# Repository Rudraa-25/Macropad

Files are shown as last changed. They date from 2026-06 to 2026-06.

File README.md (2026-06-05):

# ESP32-C3 Custom Macropad ⌨️

A fully open-source, DIY Bluetooth Macropad built with an ESP32-C3, featuring an OLED display and a dynamic **Web Bluetooth** configuration app. Configure your keymaps instantly from the web, completely wirelessly!

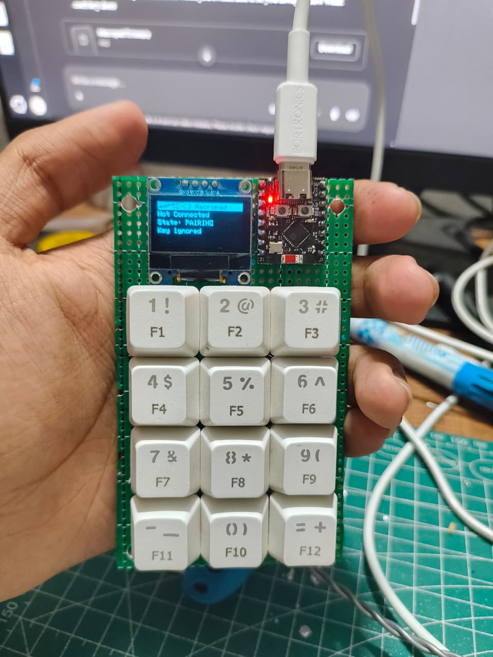
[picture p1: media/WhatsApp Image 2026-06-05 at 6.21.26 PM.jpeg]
Macropad Showcase


## ✨ Features

- **True Wireless**: Acts as a BLE (Bluetooth Low Energy) HID Keyboard. No USB required for normal use.
- **Battery Powered & Wireless**: Takes advantage of the ESP32's power efficiency to run completly on battery. Truly wireless setup for your desk!
- **Instant Web Configuration**: Includes a beautiful web application (`web-app/`) built with React and Web Bluetooth API. Re-map your keys, layers, and media controls straight from your browser without installing *any* drivers or softwere.
- **OLED Display**: Built-in SSD1306 OLED display for showing the current layer, sent keystrokes, and connetion status.
- **Multi-Layer Support**: Toggle between different key layers instantly.
- **Zero-Latency Binary Protocol**: Uses a highly optimized 384-byte binary GATT protocol to instantly fetch and save your keymap layout.

---

## 📂 Repository Structure

```
├── firmware/       # ESP32-C3 Arduino firmware code (.ino)
├── hardware/       # KiCad schematics and PDF blueprints
├── web-app/        # React + Vite web configuration tool (Vercel ready)
└── media/          # Images and video showcases of the build
```

---

## 🛠️ Hardware Requirements

- **ESP32-C3** Microcontroller
- 12x Mechanical Switches (4 Rows x 3 Cols)
- SSD1306 OLED Display (I2C)
- Custom PCB or Handwired Matrix (See `hardware/output.pdf` for the schamatic)

### Media & Build Process
Here are some behind-the-scenes looks at the build:
Schematic Process

*(More images and videos can be found in the `media/` folder!)*

---

## 🚀 Getting Started

### 1. Flash the Firmware
1. Open `firmware/Macropad.ino` in the Arduino IDE.
2. Install the required librarys (`NimBLE-Arduino`, `Adafruit GFX`, `Adafruit SSD1306`).
3. Select your ESP32-C3 board and flash it.

### 2. Pair with your OS (Important!)
Because the device acts as a secure HID Keyboard, you **must pair it in your OS settings first** (Windows/Mac/Linux) before the Web App can communicate with it.

1. Power on the ESP32-C3 Macropad.
2. Go to your computer's Bluetooth Settings and click "Add Device".
3. Pair with **"ESP32-C3 Macropad"**.

### 3. Deploy the Web App
The `web-app` folder contains the frontend configurator. You can deploy it for free using **Vercel** with zero configuration:

Deploy with Vercel (https://vercel.com/new/clone?repository-url=https://github.com/Rudraa-25/Macropad/tree/main/web-app)

Alternatively, to run it locally:
```bash
cd web-app
npm install
npm run dev
```

### 4. Configure Your Keys
1. Open your deployed web app in Google Chrome or Microsoft Edge (Safari/Firefox do not support Web Bluetooth).
2. Click **Connect Device**.
3. Re-map your keys and click Save!

---

## 🤝 Contributing
Feel free to open issues or submit pull requests. All hardware designs, firmware code, and web application code are completly open-source!

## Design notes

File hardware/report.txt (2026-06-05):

Info: Processing symbol 'SW3:'.
Info: Processing symbol 'D12:Diode_THT:D_DO-35_SOD27_P7.62mm_Horizontal'.
Info: Processing symbol 'D11:Diode_THT:D_DO-35_SOD27_P7.62mm_Horizontal'.
Info: Processing symbol 'D7:Diode_THT:D_DO-35_SOD27_P7.62mm_Horizontal'.
Info: Processing symbol 'D6:Diode_THT:D_DO-35_SOD27_P7.62mm_Horizontal'.
Info: Processing symbol 'D9:Diode_THT:D_DO-35_SOD27_P7.62mm_Horizontal'.
Info: Processing symbol 'D3:Diode_THT:D_DO-35_SOD27_P7.62mm_Horizontal'.
Info: Processing symbol 'D10:Diode_THT:D_DO-35_SOD27_P7.62mm_Horizontal'.
Info: Processing symbol 'D5:Diode_THT:D_DO-35_SOD27_P7.62mm_Horizontal'.
Info: Processing symbol 'D1:Diode_THT:D_DO-35_SOD27_P7.62mm_Horizontal'.
Info: Processing symbol 'D4:Diode_THT:D_DO-35_SOD27_P7.62mm_Horizontal'.
Info: Processing symbol 'SW1:'.
Info: Processing symbol 'SW2:'.
Info: Processing symbol 'SW4:'.
Info: Processing symbol 'D2:Diode_THT:D_DO-35_SOD27_P7.62mm_Horizontal'.
Info: Total warnings: 0, errors: 14.
Info: Processing symbol 'D8:Diode_THT:D_DO-35_SOD27_P7.62mm_Horizontal'.
Info: Processing symbol 'U2:DM-OLED096-636:MODULE_DM-OLED096-636'.
Info: Processing symbol 'U1:ESP32-C3_SUPERMINI_TH:MODULE_ESP32-C3_SUPERMINI_TH'.
Info: Processing symbol 'SW12:'.
Info: Processing symbol 'SW11:'.
Info: Processing symbol 'SW10:'.
Info: Processing symbol 'SW9:'.
Info: Processing symbol 'SW8:'.
Info: Processing symbol 'SW7:'.
Info: Processing symbol 'SW6:'.
Info: Processing symbol 'SW5:'.
Updated D9 sheetname to '/'.
Updated D9 sheetfile to 'macropad_schamatic.kicad_sch'.
Updated D9 footprint filters to 'D*DO?35*'.
Updated D9 fields.
Updated D10 symbol association from  to /3b1d06b9-a825-4d46-bb26-167e9ae0420c.
Add net Net-(D9-A).
Connected D9 pin 2 to Net-(D9-A).
Connected D9 pin 1 to /Row3.
Added D10 (footprint 'Diode_THT:D_DO-35_SOD27_P7.62mm_Horizontal').
Changed REF** reference designator to D10.
Changed D10 value from D_DO-35_SOD27_P7.62mm_Horizontal to 1N4148.
Connected D7 pin 2 to Net-(D7-A).
Updated D9 symbol association from  to /199a567d-7bb4-44c4-a2eb-34c93029b7e5.
Changed D9 value from D_DO-35_SOD27_P7.62mm_Horizontal to 1N4148.
Changed REF** reference designator to D9.
Added D9 (footprint 'Diode_THT:D_DO-35_SOD27_P7.62mm_Horizontal').
Connected D8 pin 1 to /Row3.
Connected D8 pin 2 to Net-(D8-A).
Add net Net-(D8-A).
Updated D8 footprint filters to 'D*DO?35*'.
Updated D8 sheetfile to 'macropad_schamatic.kicad_sch'.
Updated D8 sheetname to '/'.
Updated D8 fields.
Updated D8 symbol association from  to /9f40b5d8-0e24-43d8-8150-3eca3353b136.
Changed D8 value from D_DO-35_SOD27_P7.62mm_Horizontal to 1N4148.
Added D8 (footprint 'Diode_THT:D_DO-35_SOD27_P7.62mm_Horizontal').
Changed REF** reference designator to D8.
Connected D11 pin 1 to /Row4.

Connected D12 pin 2 to Net-(D12-A).
Add net Net-(D12-A).
Connected D12 pin 1 to /Row4.
Updated D12 footprint filters to 'D*DO?35*'.
Updated D12 sheetfile to 'macropad_schamatic.kicad_sch'.
Updated D12 sheetname to '/'.
Updated D12 fields.
Updated D12 symbol association from  to /22c7e66f-c951-40f0-a668-87876b066d72.
Changed D12 value from D_DO-35_SOD27_P7.62mm_Horizontal to 1N4148.
Changed REF** reference designator to D12.
Added D12 (footprint 'Diode_THT:D_DO-35_SOD27_P7.62mm_Horizontal').
Connected D11 pin 2 to Net-(D11-A).
Add net Net-(D11-A).
Updated D10 fields.
Updated D11 footprint filters to 'D*DO?35*'.
Updated D11 sheetfile to 'macropad_schamatic.kicad_sch'.
Updated D11 sheetname to '/'.
Updated D11 fields.
Updated D11 symbol association from  to /56b49147-e174-4669-9fb5-d7634ec6eaf1.
Changed D11 value from D_DO-35_SOD27_P7.62mm_Horizontal to 1N4148.
Changed REF** reference designator to D11.
Added D11 (footprint 'Diode_THT:D_DO-35_SOD27_P7.62mm_Horizontal').
Connected D10 pin 1 to /Row4.
Add net /Row4.
Connected D10 pin 2 to Net-(D10-A).
Add net Net-(D10-A).
Updated D10 footprint filters to 'D*DO?35*'.
Updated D10 sheetfile to 'macropad_schamatic.kicad_sch'.
Updated D10 sheetname to '/'.
Updated D3 sheetfile to 'macropad_schamatic.kicad_sch'.
Add net Net-(D2-A).
Connected D2 pin 2 to Net-(D2-A).
Connected D2 pin 1 to /Row1.
Added D3 (footprint 'Diode_THT:D_DO-35_SOD27_P7.62mm_Horizontal').
Changed REF** reference designator to D3.
Changed D3 value from D_DO-35_SOD27_P7.62mm_Horizontal to 1N4148.
Updated D3 symbol association from  to /08482ce4-6621-43d8-9687-0b48ae680ee7.
Updated D3 fields.
Updated D3 sheetname to '/'.
Updated D2 footprint filters to 'D*DO?35*'.
Updated D3 footprint filters to 'D*DO?35*'.
Connected D3 pin 1 to /Row1.
Add net Net-(D7-A).
Connected D3 pin 2 to Net-(D3-A).
Added D4 (footprint 'Diode_THT:D_DO-35_SOD27_P7.62mm_Horizontal').
Changed REF** reference designator to D4.
Changed D4 value from D_DO-35_SOD27_P7.62mm_Horizontal to 1N4148.
Updated D4 symbol association from  to /e49631f5-7ebc-4f1f-bee1-7b618c591ae1.
Updated D4 fields.
Connected D1 pin 2 to Net-(D1-A).
Added D1 (footprint 'Diode_THT:D_DO-35_SOD27_P7.62mm_Horizontal').
Changed REF** reference designator to D1.
Changed D1 value from D_DO-35_SOD27_P7.62mm_Horizontal to 1N4148.
Updated D1 symbol association from  to /219e1ffa-72e7-460a-b503-95e3a15a7402.
Updated D1 fields.
Updated D1 sheetname to '/'.
Updated D1 sheetfile to 'macropad_schamatic.kicad_sch'.
Updated D1 footprint filters to 'D*DO?35*'.
Add net Net-(D1-A).
Add net Net-(D3-A).
Add net /Row1.
Connected D1 pin 1 to /Row1.
Added D2 (footprint 'Diode_THT:D_DO-35_SOD27_P7.62mm_Horizontal').
Changed REF** reference designator to D2.
Changed D2 value from D_DO-35_SOD27_P7.62mm_Horizontal to 1N4148.
Updated D2 symbol association from  to /d1962255-4c64-4023-9314-8b50c877019e.
Updated D2 fields.
Updated D2 sheetname to '/'.
Updated D2 sheetfile to 'macropad_schamatic.kicad_sch'.
Added D7 (footprint 'Diode_THT:D_DO-35_SOD27_P7.62mm_Horizontal').
Changed D6 value from D_DO-35_SOD27_P7.62mm_Horizontal to 1N4148.
Updated D6 symbol association from  to /b3993612-8098-4776-a2f9-317e4327c308.
Updated D6 fields.
Updated D6 sheetname to '/'.
Updated D4 sheetname to '/'.
Updated D6 footprint filters to 'D*DO?35*'.
Add net Net-(D6-A).
Connected D6 pin 2 to Net-(D6-A).
Connected D6 pin 1 to /Row2.
Updated D6 sheetfile to 'macropad_schamatic.kicad_sch'.
Changed REF** reference designator to D7.
Changed D7 value from D_DO-35_SOD27_P7.62mm_Horizontal to 1N4148.
Updated D7 symbol association from  to /181c0100-887a-4238-aaa2-16277b3d4ceb.
Updated D7 fields.
Updated D7 sheetname to '/'.
Updated D7 sheetfile to 'macropad_schamatic.kicad_sch'.
Updated D7 footprint filters to 'D*DO?35*'.
Add net /Row3.
Connected D7 pin 1 to /Row3.
Updated D5 symbol association from  to /a2443731-23b2-4b6e-a306-a3f56fe90480.
Updated D4 sheetfile to 'macropad_schamatic.kicad_sch'.
Updated D4 footprint filters to 'D*DO?35*'.
Add net Net-(D4-A).
Connected D4 pin 2 to Net-(D4-A).
Add net /Row2.
Connected D4 pin 1 to /Row2.
Added D5 (footprint 'Diode_THT:D_DO-35_SOD27_P7.62mm_Horizontal').
Changed REF** reference designator to D5.
Changed D5 value from D_DO-35_SOD27_P7.62mm_Horizontal to 1N4148.
Changed REF** reference designator to D6.
Updated D5 fields.
Added D6 (footprint 'Diode_THT:D_DO-35_SOD27_P7.62mm_Horizontal').
Connected D5 pin 2 to Net-(D5-A).
Updated D5 sheetfile to 'macropad_schamatic.kicad_sch'.
Add net Net-(D5-A).
Updated D5 footprint filters to 'D*DO?35*'.
Updated D5 sheetname to '/'.
Connected D5 pin 1 to /Row2.
Error: Cannot add SW3 (no footprint assigned).
Error: Cannot add SW1 (no footprint assigned).
Error: Cannot add U2 (footprint 'DM-OLED096-636:MODULE_DM-OLED096-636' not found).
Error: Cannot add U1 (footprint 'ESP32-C3_SUPERMINI_TH:MODULE_ESP32-C3_SUPERMINI_TH' not found).
Error: Cannot add SW2 (no footprint assigned).
Error: Cannot add SW12 (no footprint assigned).
Error: Cannot add SW11 (no footprint assigned).
Error: Cannot add SW10 (no footprint assigned).
Error: Cannot add SW9 (no footprint assigned).
Error: Cannot add SW4 (no footprint assigned).
Error: Cannot add SW8 (no footprint assigned).
Error: Cannot add SW7 (no footprint assigned).
Error: Cannot add SW5 (no footprint assigned).
Error: Cannot add SW6 (no footprint assigned).

Info: Total warnings: 0, errors: 14.

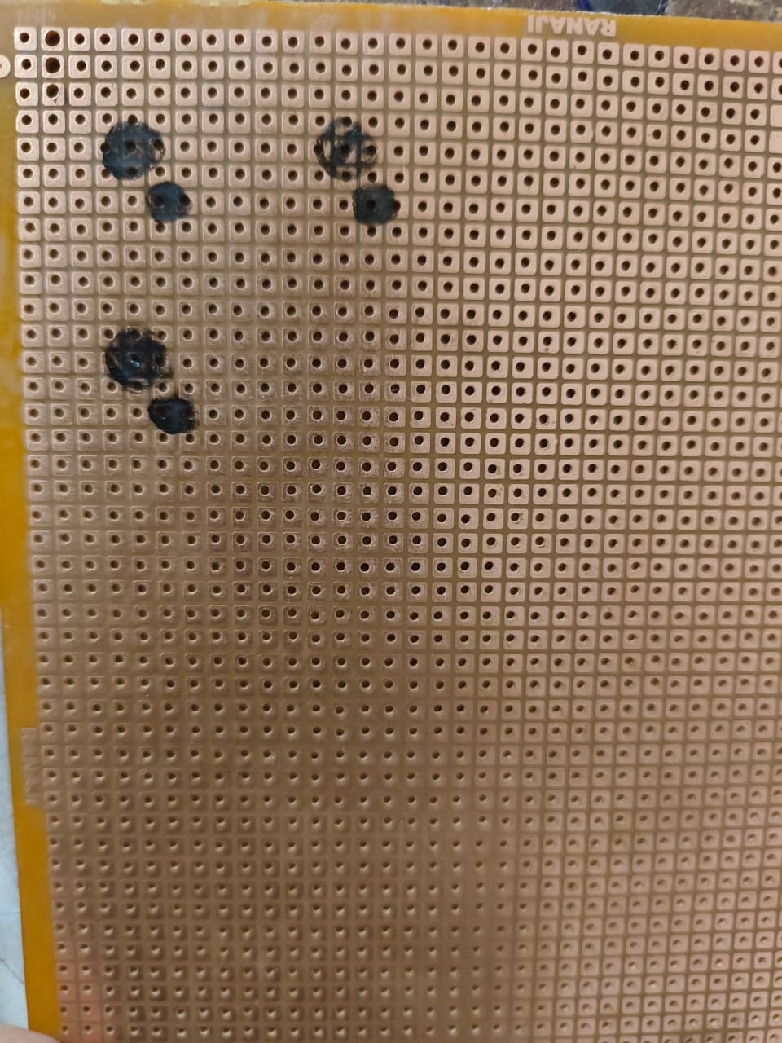
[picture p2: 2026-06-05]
media/WhatsApp Image 2026-06-05 at 6.21.24 PM.jpeg

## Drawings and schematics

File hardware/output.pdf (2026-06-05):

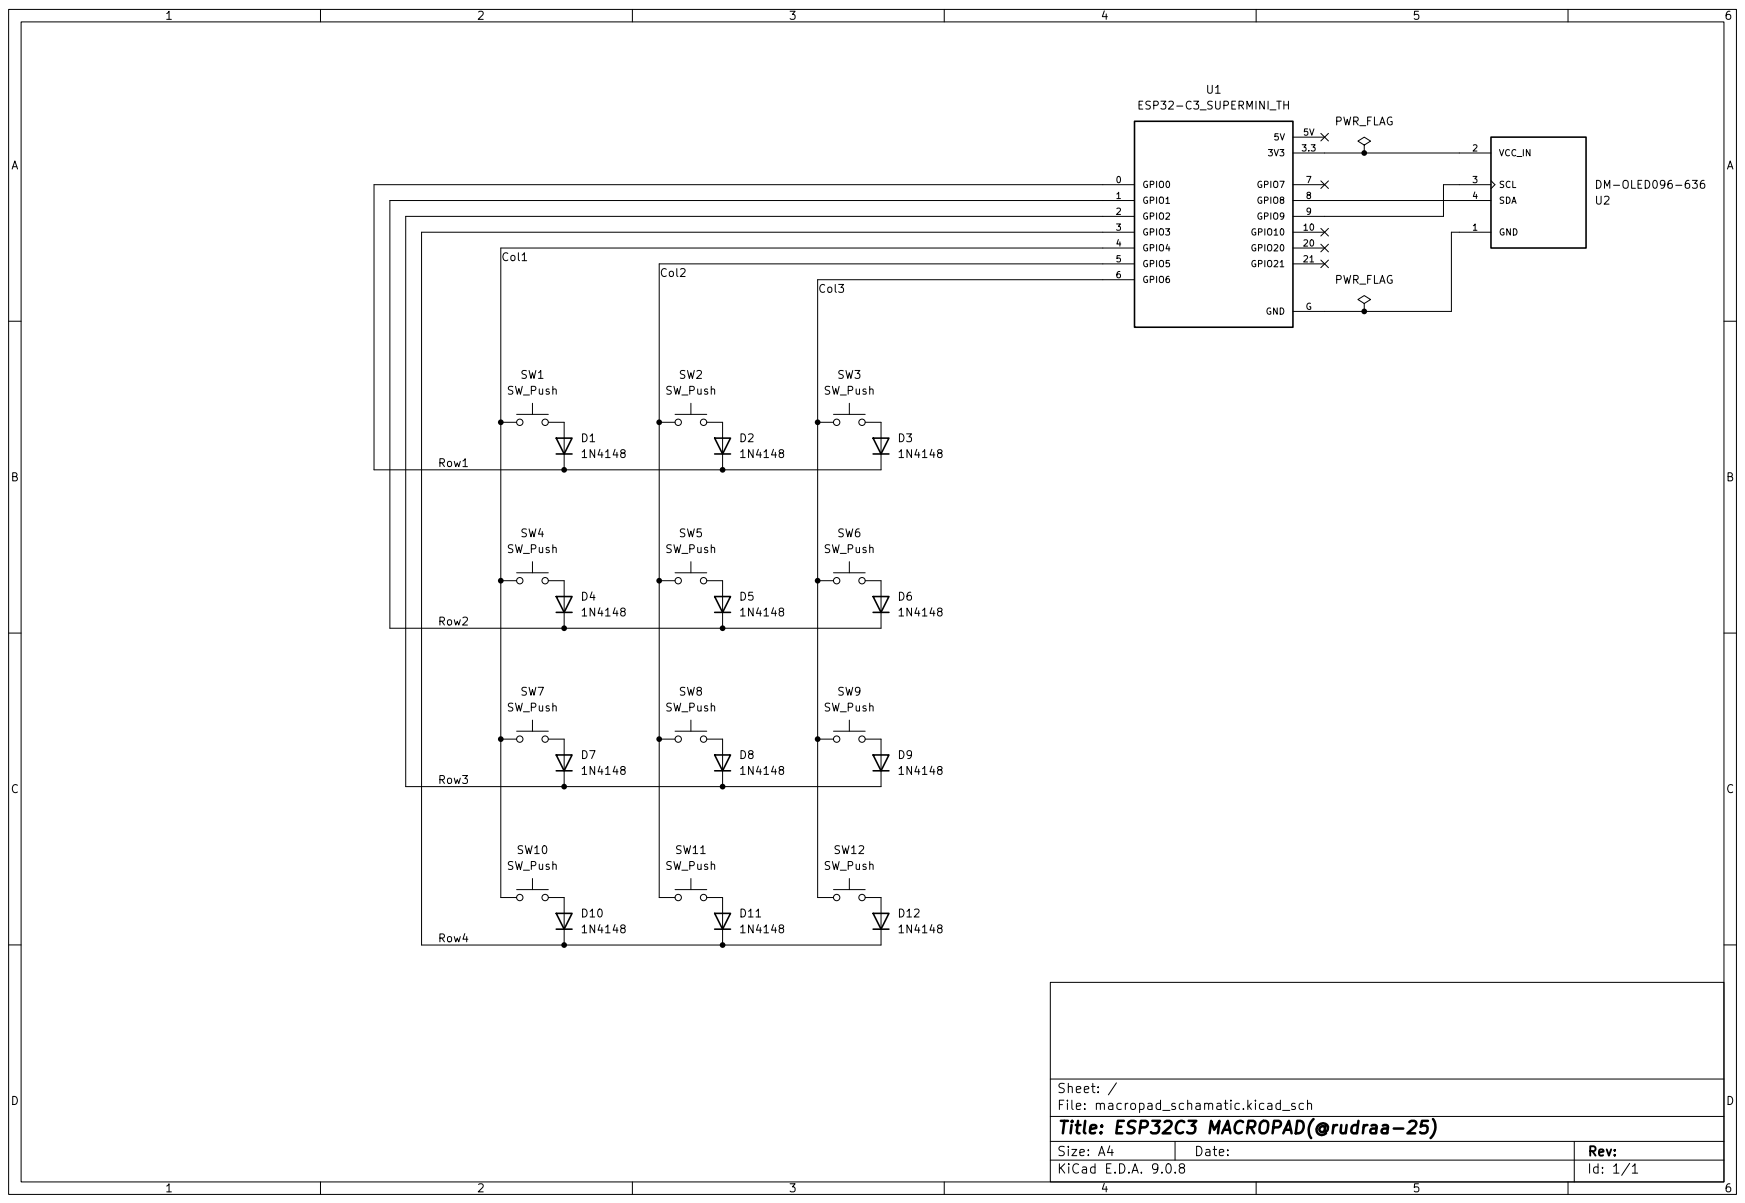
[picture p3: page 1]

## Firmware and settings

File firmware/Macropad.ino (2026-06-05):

// ============================================================
//  ESP32-C3 BLE Macropad -- Firmware v8
//
//  ARCHITECTURE CHANGE FROM v7:
//    WiFi / config mode REMOVED entirely.
//    The device is ALWAYS a BLE keyboard.
//    Configuration is done via a second BLE GATT service
//    running alongside the HID service.
//    The Lovable web app uses Web Bluetooth API to connect
//    and read/write keymap characteristics directly.
//
//  BLE SERVICES:
//    1. HID Service (standard)       -- keyboard input
//    2. Config Service (custom GATT) -- keymap read/write
//       Service UUID:  12345678-1234-1234-1234-1234567890AB
//       Characteristics:
//         STATUS_UUID:  read  -- JSON device info
//         KEYMAP_UUID:  read  -- full keymap JSON
//         SAVE_UUID:    write -- post updated keymap JSON
//
//  HOW TO USE:
//    Just power on -- it advertises as a BLE keyboard AND config target.
//    Open the Lovable web app in Chrome/Edge on phone or desktop.
//    Click "Connect Device" -- browser shows BLE pairing dialog.
//    Select "ESP32-C3 Macropad" -- app reads keymap, lets you edit, saves.
//    Keyboard still works while config app is connected.
// ============================================================

#include <Arduino.h>
#include <Preferences.h>
#include <Wire.h>
#include <Adafruit_GFX.h>
#include <Adafruit_SSD1306.h>
#include <NimBLEDevice.h>
#include <NimBLEServer.h>
#include <NimBLEUtils.h>
#include <NimBLEHIDDevice.h>
#include <HIDTypes.h>

// ============================================================
//  CONFIG
// ============================================================
#define DEVICE_NAME       "ESP32-C3 Macropad"
#define MANUFACTURER_NAME "DIY"

// Custom GATT UUIDs for the config service
// These must match exactly in the Lovable web app
#define CONFIG_SERVICE_UUID  "12345678-1234-1234-1234-1234567890ab"
#define STATUS_CHAR_UUID     "12345678-1234-1234-1234-1234567890ac"
#define KEYMAP_CHAR_UUID     "12345678-1234-1234-1234-1234567890ad"
#define SAVE_CHAR_UUID       "12345678-1234-1234-1234-1234567890ae"

// ============================================================
//  OLED
// ============================================================
#define SCREEN_W   128
#define SCREEN_H    64
#define OLED_ADDR  0x3C
#define OLED_SDA     8
#define OLED_SCL     9

// ============================================================
//  MATRIX
// ============================================================
#define ROWS 4
#define COLS 3
const int rowPins[ROWS] = {0, 1, 2, 3};
const int colPins[COLS] = {5, 6, 7};

#define DEBOUNCE_MS    150
#define ADV_RESTART_MS 500
#define MTU_SIZE       512   // increased for keymap JSON transfer
#define NUM_KEYS       (ROWS * COLS)
#define NUM_LAYERS     2

// ============================================================
//  HID constants
// ============================================================
#define MOD_NONE  0x00
#define MOD_CTRL  0x01
#define MOD_SHIFT 0x02
#define MOD_ALT   0x04
#define MOD_GUI   0x08

#define KEY_NONE  0x00
#define KEY_0     0x27
#define KEY_1     0x1E
#define KEY_2     0x1F
#define KEY_3     0x20
#define KEY_4     0x21
#define KEY_5     0x22
#define KEY_6     0x23
#define KEY_7     0x24
#define KEY_8     0x25
#define KEY_9     0x26
#define KEY_A     0x04
#define KEY_B     0x05
#define KEY_C     0x06
#define KEY_D     0x07
#define KEY_E     0x08
#define KEY_F     0x09
#define KEY_G     0x0A
#define KEY_H     0x0B
#define KEY_I     0x0C
#define KEY_J     0x0D
#define KEY_K     0x0E
#define KEY_L     0x0F
#define KEY_M     0x10
#define KEY_N     0x11
#define KEY_O     0x12
#define KEY_P     0x13
#define KEY_Q     0x14
#define KEY_R     0x15
#define KEY_S     0x16
#define KEY_T     0x17
#define KEY_U     0x18
#define KEY_V     0x19
#define KEY_W     0x1A
#define KEY_X     0x1B
#define KEY_Y     0x1C
#define KEY_Z     0x1D
#define KEY_F1    0x3A
#define KEY_F2    0x3B
#define KEY_F3    0x3C
#define KEY_F4    0x3D
#define KEY_F5    0x3E
#define KEY_F6    0x3F
#define KEY_F7    0x40
#define KEY_F8    0x41
#define KEY_F9    0x42
#define KEY_F10   0x43
#define KEY_F11   0x44
#define KEY_F12   0x45
#define KEY_ESC   0x29
#define KEY_TAB   0x2B
#define KEY_DEL   0x4C
#define KEY_HOME  0x4A
#define KEY_END   0x4D
#define KEY_PGUP  0x4B
#define KEY_PGDN  0x4E
#define KEY_UP    0x52
#define KEY_DOWN  0x51
#define KEY_LEFT  0x50
#define KEY_RIGHT 0x4F
#define KEY_ENTER 0x28
#define KEY_SPACE 0x2C
#define KEY_BKSP  0x2A

#define CONSUMER_VOL_UP   0xE9
#define CONSUMER_VOL_DOWN 0xEA
#define CONSUMER_MUTE     0xE2

#define ACTION_NONE         0
#define ACTION_LAYER_TOGGLE 1
#define ACTION_VOLUME_UP    2
#define ACTION_VOLUME_DOWN  3
#define ACTION_MUTE         4

// ============================================================
//  Data
// ============================================================
struct KeyDef {
  uint8_t mod;
  uint8_t keycode;
  uint8_t action;
  char    label[12];
};

KeyDef keyMap[NUM_LAYERS][ROWS][COLS] = {
  // Layer 0: Numbers
  {
    { {MOD_NONE,KEY_1,ACTION_NONE,"1"},    {MOD_NONE,KEY_2,ACTION_NONE,"2"},    {MOD_NONE,KEY_3,ACTION_NONE,"3"}    },
    { {MOD_NONE,KEY_4,ACTION_NONE,"4"},    {MOD_NONE,KEY_5,ACTION_NONE,"5"},    {MOD_NONE,KEY_6,ACTION_NONE,"6"}    },
    { {MOD_NONE,KEY_7,ACTION_NONE,"7"},    {MOD_NONE,KEY_8,ACTION_NONE,"8"},    {MOD_NONE,KEY_9,ACTION_NONE,"9"}    },
    { {MOD_NONE,KEY_NONE,ACTION_VOLUME_UP,"VolUp"}, {MOD_NONE,KEY_0,ACTION_NONE,"0"}, {MOD_NONE,KEY_NONE,ACTION_LAYER_TOGGLE,"MODE"} },
  },
  // Layer 1: Shortcuts
  {
    { {MOD_CTRL,KEY_Z,ACTION_NONE,"Ctrl+Z"}, {MOD_CTRL,KEY_S,ACTION_NONE,"Ctrl+S"}, {MOD_CTRL,KEY_A,ACTION_NONE,"Ctrl+A"} },
    { {MOD_CTRL,KEY_X,ACTION_NONE,"Ctrl+X"}, {MOD_CTRL,KEY_Y,ACTION_NONE,"Ctrl+Y"}, {MOD_GUI, KEY_D,ACTION_NONE,"Win+D"}  },
    { {MOD_ALT, KEY_F4,ACTION_NONE,"Alt+F4"},{MOD_CTRL,KEY_W,ACTION_NONE,"Ctrl+W"}, {MOD_CTRL,KEY_T,ACTION_NONE,"Ctrl+T"} },
    { {MOD_NONE,KEY_NONE,ACTION_VOLUME_DOWN,"VolDn"}, {MOD_NONE,KEY_0,ACTION_NONE,"0"}, {MOD_NONE,KEY_NONE,ACTION_LAYER_TOGGLE,"MODE"} },
  }
};

// ============================================================
//  Globals
// ============================================================
Preferences            prefs;
NimBLEHIDDevice*       hid           = nullptr;
NimBLECharacteristic*  inputKbd      = nullptr;
NimBLECharacteristic*  inputConsumer = nullptr;
NimBLEServer*          pServer       = nullptr;
NimBLECharacteristic*  cfgStatusChar = nullptr;
NimBLECharacteristic*  cfgKeymapChar = nullptr;
NimBLECharacteristic*  cfgSaveChar   = nullptr;
Adafruit_SSD1306       display(SCREEN_W, SCREEN_H, &Wire, -1);
bool                   oledOk        = false;
int                    currentLayer  = 0;
bool                   configClientConnected = false;

enum class BleState { INIT, ADVERTISING, PAIRING, CONNECTED, DISCONNECTED };
volatile BleState bleState  = BleState::INIT;
volatile bool     needReAdv = false;
uint32_t          connectedAt = 0;

// ============================================================
//  Forward declarations
// ============================================================
void updateOLED(const char* l1, const char* l2, const char* l3, const char* l4 = "");
void startAdvertising();
void sendKey(uint8_t mod, uint8_t kc);
void sendConsumer(uint8_t usage);
void showLayerScreen();
void saveKeyMap();
void loadKeyMap();
const char* stateName(BleState s);
String buildKeymapJson();
bool parseAndApplyKeymap(const String& json);

// ============================================================
//  NVS
// ============================================================
void saveKeyMap() {
  prefs.begin("keymap", false);
  for (int layer = 0; layer < NUM_LAYERS; layer++) {
    for (int r = 0; r < ROWS; r++) {
      for (int c = 0; c < COLS; c++) {
        int idx = layer * NUM_KEYS + r * COLS + c;
        char km[8], kk[8], ka[8], kl[8];
        snprintf(km,8,"m%d",idx); snprintf(kk,8,"k%d",idx);
        snprintf(ka,8,"a%d",idx); snprintf(kl,8,"l%d",idx);
        prefs.putUChar(km, keyMap[layer][r][c].mod);
        prefs.putUChar(kk, keyMap[layer][r][c].keycode);
        prefs.putUChar(ka, keyMap[layer][r][c].action);
        prefs.putString(kl, keyMap[layer][r][c].label);
      }
    }
  }
  prefs.end();
  Serial.println("[NVS] Saved");
}

void loadKeyMap() {
  prefs.begin("keymap", true);
  if (!prefs.isKey("m0")) { prefs.end(); Serial.println("[NVS] Using defaults"); return; }
  for (int layer = 0; layer < NUM_LAYERS; layer++) {
    for (int r = 0; r < ROWS; r++) {
      for (int c = 0; c < COLS; c++) {
        int idx = layer * NUM_KEYS + r * COLS + c;
        char km[8], kk[8], ka[8], kl[8];
        snprintf(km,8,"m%d",idx); snprintf(kk,8,"k%d",idx);
        snprintf(ka,8,"a%d",idx); snprintf(kl,8,"l%d",idx);
        keyMap[layer][r][c].mod     = prefs.getUChar(km, keyMap[layer][r][c].mod);
        keyMap[layer][r][c].keycode = prefs.getUChar(kk, keyMap[layer][r][c].keycode);
        keyMap[layer][r][c].action  = prefs.getUChar(ka, keyMap[layer][r][c].action);
        String lbl = prefs.getString(kl, keyMap[layer][r][c].label);
        strncpy(keyMap[layer][r][c].label, lbl.c_str(), 11);
        keyMap[layer][r][c].label[11] = '\0';
      }
    }
  }
  prefs.end();
  Serial.println("[NVS] Loaded");
}

// ============================================================
//  JSON helpers
// ============================================================
String buildKeymapJson() {
  // Compact JSON: {"layers":2,"keys":12,"keymap":[[{...},...],[...]]}
  String s = "{\"layers\":";
  s += NUM_LAYERS;
  s += ",\"keys\":";
  s += NUM_KEYS;
  s += ",\"keymap\":[";
  for (int layer = 0; layer < NUM_LAYERS; layer++) {
    s += "[";
    for (int r = 0; r < ROWS; r++) {
      for (int c = 0; c < COLS; c++) {
        KeyDef& k = keyMap[layer][r][c];
        int idx = r * COLS + c;
        s += "{\"i\":";   s += idx;
        s += ",\"l\":";   s += layer;
        s += ",\"m\":";   s += k.mod;
        s += ",\"k\":";   s += k.keycode;
        s += ",\"a\":";   s += k.action;
        s += ",\"n\":\"";
        for (int i = 0; k.label[i] && i < 11; i++) {
          char ch = k.label[i];
          if (ch == '"') s += "\\\"";
          else if (ch == '\\') s += "\\\\";
          else s += ch;
        }
        s += "\"}";
        if (!(r == ROWS-1 && c == COLS-1)) s += ",";
      }
    }
    s += "]";
    if (layer < NUM_LAYERS-1) s += ",";
  }
  s += "]}";
  return s;
}

// Parse the keymap JSON sent from the web app and apply to keyMap[]
// Expected format: {"keymap":[[{i,l,m,k,a,n},...],[...]]}
bool parseAndApplyKeymap(const String& json) {
  int found = 0;
  int pos = 0;
  while (pos < (int)json.length()) {
    int ii = json.indexOf("\"i\":", pos);  if (ii < 0) break;
    int li = json.indexOf("\"l\":", ii);   if (li < 0) break;
    int mi = json.indexOf("\"m\":", ii);   if (mi < 0) break;
    int ki = json.indexOf("\"k\":", ii);   if (ki < 0) break;
    int ai = json.indexOf("\"a\":", ii);   if (ai < 0) break;
    int ni = json.indexOf("\"n\":\"", ii); if (ni < 0) break;

    int idx   = json.substring(ii+4).toInt();
    int layer = json.substring(li+4).toInt();
    uint8_t mod = (uint8_t)json.substring(mi+4).toInt();
    uint8_t kc  = (uint8_t)json.substring(ki+4).toInt();
    uint8_t act = (uint8_t)json.substring(ai+4).toInt();

    int ne = json.indexOf("\"", ni+5);
    String lbl = (ne > ni+5) ? json.substring(ni+5, ne) : "";

    if (layer >= 0 && layer < NUM_LAYERS && idx >= 0 && idx < NUM_KEYS) {
      int r = idx / COLS, c = idx % COLS;
      keyMap[layer][r][c].mod     = mod;
      keyMap[layer][r][c].keycode = kc;
      keyMap[layer][r][c].action  = act;
      strncpy(keyMap[layer][r][c].label, lbl.c_str(), 11);
      keyMap[layer][r][c].label[11] = '\0';
      found++;
    }
    pos = (ne > 0) ? ne + 1 : pos + 1;
  }
  Serial.printf("[BLE-CFG] Parsed %d keys\n", found);
  return found > 0;
}

// ============================================================
//  GATT Config characteristic callbacks
// ============================================================

// SAVE characteristic -- web app writes updated keymap JSON here
class SaveCharCallbacks : public NimBLECharacteristicCallbacks {
  void onWrite(NimBLECharacteristic* pChr, NimBLEConnInfo& ci) override {
    String val = pChr->getValue().c_str();
    Serial.printf("[BLE-CFG] Received save payload (%d bytes)\n", val.length());

    bool ok = parseAndApplyKeymap(val);
    if (ok) {
      saveKeyMap();
      updateOLED("Config", "Keymap saved!", "via BLE", "");
      delay(1500);
      showLayerScreen();
      // Echo back success
      cfgSaveChar->setValue("{\"ok\":true}");
    } else {
      Serial.println("[BLE-CFG] Parse failed");
      cfgSaveChar->setValue("{\"ok\":false}");
    }
  }
};

// ============================================================
//  BLE Server callbacks (HID)
// ============================================================
class ServerCallbacks : public NimBLEServerCallbacks {
  void onConnect(NimBLEServer* pSrv, NimBLEConnInfo& ci) override {
    bleState = BleState::PAIRING;
    Serial.printf("[BLE] Host connected: %s\n", ci.getAddress().toString().c_str());
    updateOLED("BLE", "Pairing...", ci.getAddress().toString().c_str());
    pSrv->setDataLen(ci.getConnHandle(), MTU_SIZE);
    NimBLEDevice::setMTU(MTU_SIZE);
  }
  void onDisconnect(NimBLEServer* pSrv, NimBLEConnInfo& ci, int reason) override {
    bleState  = BleState::DISCONNECTED;
    needReAdv = true;
    configClientConnected = false;
    Serial.printf("[BLE] Disconnected: 0x%02X\n", reason);
    updateOLED("BLE", "Disconnected", "Re-advertising...");
  }
  void onAuthenticationComplete(NimBLEConnInfo& ci) override {
    if (ci.isEncrypted()) {
      bleState    = BleState::CONNECTED;
      connectedAt = millis();
      Serial.println("[BLE] Authenticated -- HID + Config ready");
      showLayerScreen();
    } else {
      Serial.println("[BLE] Auth failed -- removing bond");
      NimBLEDevice::deleteBond(ci.getAddress());
      NimBLEDevice::getServer()->disconnect(ci.getConnHandle());
    }
  }
};

// ============================================================
//  OLED helpers
// ============================================================
void updateOLED(const char* l1, const char* l2, const char* l3, const char* l4) {
  if (!oledOk) return;
  display.clearDisplay();
  display.setTextSize(1);
  display.fillRect(0, 0, SCREEN_W, 10, SSD1306_WHITE);
  display.setTextColor(SSD1306_BLACK);
  display.setCursor(2, 1);
  display.print(DEVICE_NAME);
  display.setTextColor(SSD1306_WHITE);
  if (bleState == BleState::CONNECTED)
    display.fillCircle(SCREEN_W-5, 5, 3, SSD1306_BLACK);
  display.setCursor(0, 13); display.print(l1);
  display.setCursor(0, 25); display.print(l2);
  display.setCursor(0, 37); display.print(l3);
  display.setCursor(0, 49); display.print(l4);
  display.display();
}

void showLayerScreen() {
  char top[32];
  snprintf(top, sizeof(top), "Layer %d: %s", currentLayer, currentLayer==0 ? "Numbers" : "Shortcuts");
  updateOLED(top,
             currentLayer==0 ? "1-9  0  VolUp" : "C+Z C+S C+A",
             currentLayer==0 ? "K11=MODE" : "C+X C+Y Win+D",
             "BLE: keyboard+cfg");
}

// ============================================================
//  BLE start advertising
// ============================================================
void startAdvertising() {
  NimBLEAdvertising* pAdv = NimBLEDevice::getAdvertising();
  pAdv->reset();
  pAdv->setAppearance(HID_KEYBOARD);
  pAdv->addServiceUUID(hid->getHidService()->getUUID());
  pAdv->addServiceUUID(CONFIG_SERVICE_UUID);
  NimBLEAdvertisementData sr;
  sr.setName(DEVICE_NAME);
  pAdv->setScanResponseData(sr);
  pAdv->enableScanResponse(true);
  pAdv->setMinInterval(0x20);
  pAdv->setMaxInterval(0x40);
  bleState = BleState::ADVERTISING;
  if (pAdv->start()) {
    Serial.println("[BLE] Advertising HID + Config");
    updateOLED("BLE Advertising", "Keyboard + Config", "Open web app", "to configure");
  } else {
    Serial.println("[BLE] Advertising FAILED");
    updateOLED("BLE", "ADV FAILED", "Reset device", "");
  }
}

// ============================================================
//  HID key sending
// ============================================================
void sendKey(uint8_t mod, uint8_t kc) {
  if (bleState != BleState::CONNECTED || !inputKbd) return;
  uint8_t d[8] = {mod, 0, kc, 0, 0, 0, 0, 0};
  uint8_t r[8] = {0};
  inputKbd->setValue(d, 8); inputKbd->notify(); delay(12);
  inputKbd->setValue(r, 8); inputKbd->notify(); delay(12);
}

void sendConsumer(uint8_t usage) {
  if (bleState != BleState::CONNECTED || !inputConsumer) return;
  uint8_t p[2] = {usage, 0};
  uint8_t r[2] = {0, 0};
  inputConsumer->setValue(p, 2); inputConsumer->notify(); delay(12);
  inputConsumer->setValue(r, 2); inputConsumer->notify(); delay(12);
}

const char* stateName(BleState s) {
  switch(s) {
    case BleState::INIT:         return "INIT";
    case BleState::ADVERTISING:  return "ADV";
    case BleState::PAIRING:      return "PAIRING";
    case BleState::CONNECTED:    return "CONNECTED";
    case BleState::DISCONNECTED: return "DISCONNECTED";
    default:                     return "UNKNOWN";
  }
}
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
void loop() {
  if (needReAdv) {
    needReAdv = false;
    delay(ADV_RESTART_MS);
    // Refresh keymap char before re-advertising
    // so next connect always gets fresh data
    if (cfgKeymapChar) cfgKeymapChar->setValue(buildKeymapJson().c_str());
    startAdvertising();
  }

  // Matrix scan
  for (int r = 0; r < ROWS; r++) {
    digitalWrite(rowPins[r], LOW);
    delayMicroseconds(10);
    for (int c = 0; c < COLS; c++) {
      if (digitalRead(colPins[c]) == LOW) {
        const KeyDef& k = keyMap[currentLayer][r][c];
        int kn = r * COLS + c;
        Serial.printf("[KEY] K%d -> %s (L%d state:%s)\n", kn, k.label, currentLayer, stateName(bleState));

        if (k.action == ACTION_LAYER_TOGGLE) {
          currentLayer = (currentLayer == 0) ? 1 : 0;
          showLayerScreen();
          delay(DEBOUNCE_MS);
          digitalWrite(rowPins[r], HIGH);
          return;
        }

        if (bleState != BleState::CONNECTED) {
          char buf[24];
          snprintf(buf, sizeof(buf), "State: %s", stateName(bleState));
          updateOLED("Not Ready", buf, "Key ignored", "");
          delay(DEBOUNCE_MS);
          continue;
        }

        if (k.action == ACTION_VOLUME_UP)   { sendConsumer(CONSUMER_VOL_UP);   updateOLED("Sent:","Vol Up",  "",""); delay(DEBOUNCE_MS); showLayerScreen(); digitalWrite(rowPins[r],HIGH); return; }
        if (k.action == ACTION_VOLUME_DOWN) { sendConsumer(CONSUMER_VOL_DOWN); updateOLED("Sent:","Vol Down","",""); delay(DEBOUNCE_MS); showLayerScreen(); digitalWrite(rowPins[r],HIGH); return; }
        if (k.action == ACTION_MUTE)        { sendConsumer(CONSUMER_MUTE);     updateOLED("Sent:","Mute",    "",""); delay(DEBOUNCE_MS); showLayerScreen(); digitalWrite(rowPins[r],HIGH); return; }

        char buf[24];
        snprintf(buf, sizeof(buf), "K%d: %s", kn, k.label);
        updateOLED("Sent:", buf, "", "");
        sendKey(k.mod, k.keycode);
        delay(DEBOUNCE_MS);
        showLayerScreen();
      }
    }
    digitalWrite(rowPins[r], HIGH);
  }
}

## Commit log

2026-06-05 v6: Hold K9+K11 for 3s to enter config mode (no reboot), BLE stops cleanly before WiFi starts
    [v6.ino]
2026-06-05 v5: Hold K0 at boot for config mode, fixed BLE/WiFi radio conflict, no deleteAllBonds on boot
    [v5.ino]
2026-06-05 v3: Added WiFi AP + Web Configurator, PIN login, OLED status display
2026-06-05 v2: 2 layers (Numbers/Shortcuts), Volume Up, Layer Toggle, consumer HID reports
    [v2.ino]
2026-06-05 Organize monorepo structure, add web app and media, and update README
    [macropad_schamatic.kicad_pcb, macropad_schamatic.kicad_sch]
2026-06-05 Update README with battery powered feature and humanized tone
